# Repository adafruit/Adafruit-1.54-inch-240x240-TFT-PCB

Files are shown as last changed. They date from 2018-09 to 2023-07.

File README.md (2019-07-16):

## Adafruit 1.54" 240x240 Wide Angle TFT LCD Display with MicroSD - ST7789 PCB

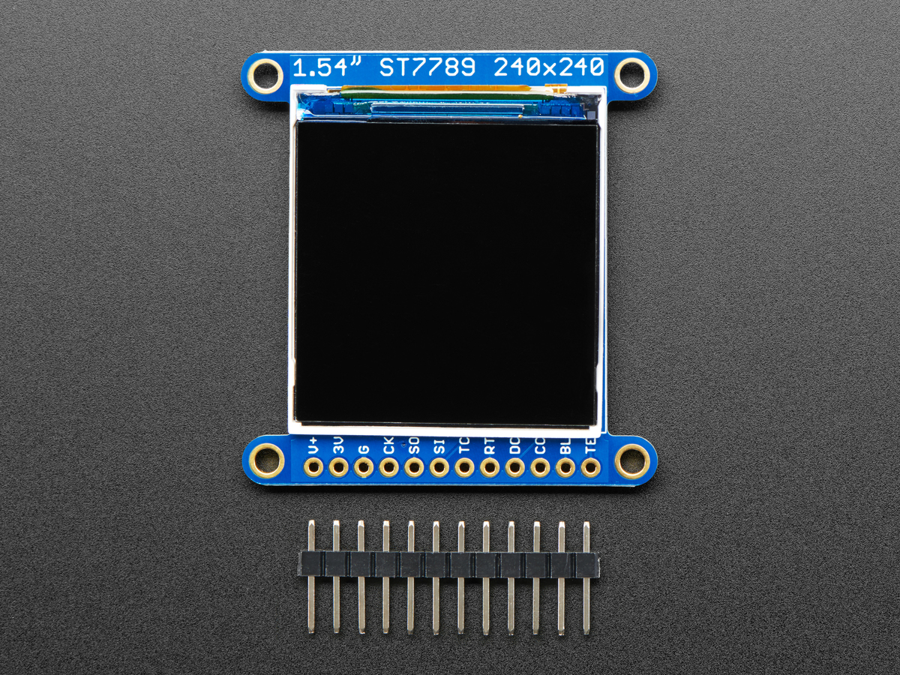
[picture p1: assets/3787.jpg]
<a href="http://www.adafruit.com/products/3787"><br/>
Click here to purchase one from the Adafruit shop</a>

PCB files for the Adafruit 1.54" 240x240 Wide Angle TFT LCD Display with MicroSD - ST7789. Format is EagleCAD schematic and board layout
* https://www.adafruit.com/product/3787

### Description

We've been looking for a display like this for a long time - it's only 1.5" diagonal but has a high density 220 ppi, 240x240 pixel display with full-angle viewing. It looks a lot like our 1.44" 128x128 display, but has 4x as many pixels and looks great at any angle. We've seen displays of this caliber used in smartwatches and small electronic devices but they've always been MIPI interface. Finally, we found one that is SPI and has a friendly display driver, so it works with any and all microcontrollers or microcomputers!

This lovely little display breakout is the best way to add a small, colorful and very bright display to any project. Since the display uses 4-wire SPI to communicate and has its own pixel-addressable frame buffer, it can be used with every kind of microcontroller. Even a very small one with low memory and few pins available! The 1.54" display has 240x240 16-bit full color pixels and is an **IPS** display, so the color looks great up to 80 degrees off axis in any direction. The TFT driver (ST7789) is very similar to the popular ST7735, and our Arduino library supports it well.

Our breakout has the TFT display soldered on (it uses a delicate flex-circuit connector) as well as a ultra-low-dropout 3.3V regulator and a 3/5V level shifter so you can use it with 3.3V or 5V power and logic. We also had a little space so we placed a microSD card holder so you can easily load full color bitmaps from a FAT16/FAT32 formatted microSD card. The microSD card is not included, [but you can pick one up here](http://www.adafruit.com/products/102) .

Of course, we wouldn't just leave you with a datasheet and a "good luck!" - [we've written a full open source graphics library that can draw pixels, lines, rectangles, circles, text and bitmaps as well as example code and a wiring tutorial.](http://learn.adafruit.com/1-8-tft-display) The code is written for Arduino but can be easily ported to your favorite microcontroller!

**Please note!** This display is designed original for smart watches and similar, where there's a glass over the screen. Without something gently holding the screen down, the backlight can eventually peel away from the TFT. (It's not destructive but it's unattractive) You can prevent this by, ideally, adding a plastic or glass cover/overlay. If using bare, try dabbing a touch of T6000 or similar craft glue on the thin side edges, or using a thin piece of tape to keep the front TFT attached to the backlight. We're trying to find a display without this annoyance, but these displays don't have a lot of manufacturers so pickin's are slim!

### License

Adafruit invests time and resources providing this open source design, please support Adafruit and open-source hardware by purchasing products from [Adafruit](https://www.adafruit.com)!

Designed by Limor Fried/Ladyada for Adafruit Industries.

Creative Commons Attribution/Share-Alike, all text above must be included in any redistribution. See license.txt for additional details.

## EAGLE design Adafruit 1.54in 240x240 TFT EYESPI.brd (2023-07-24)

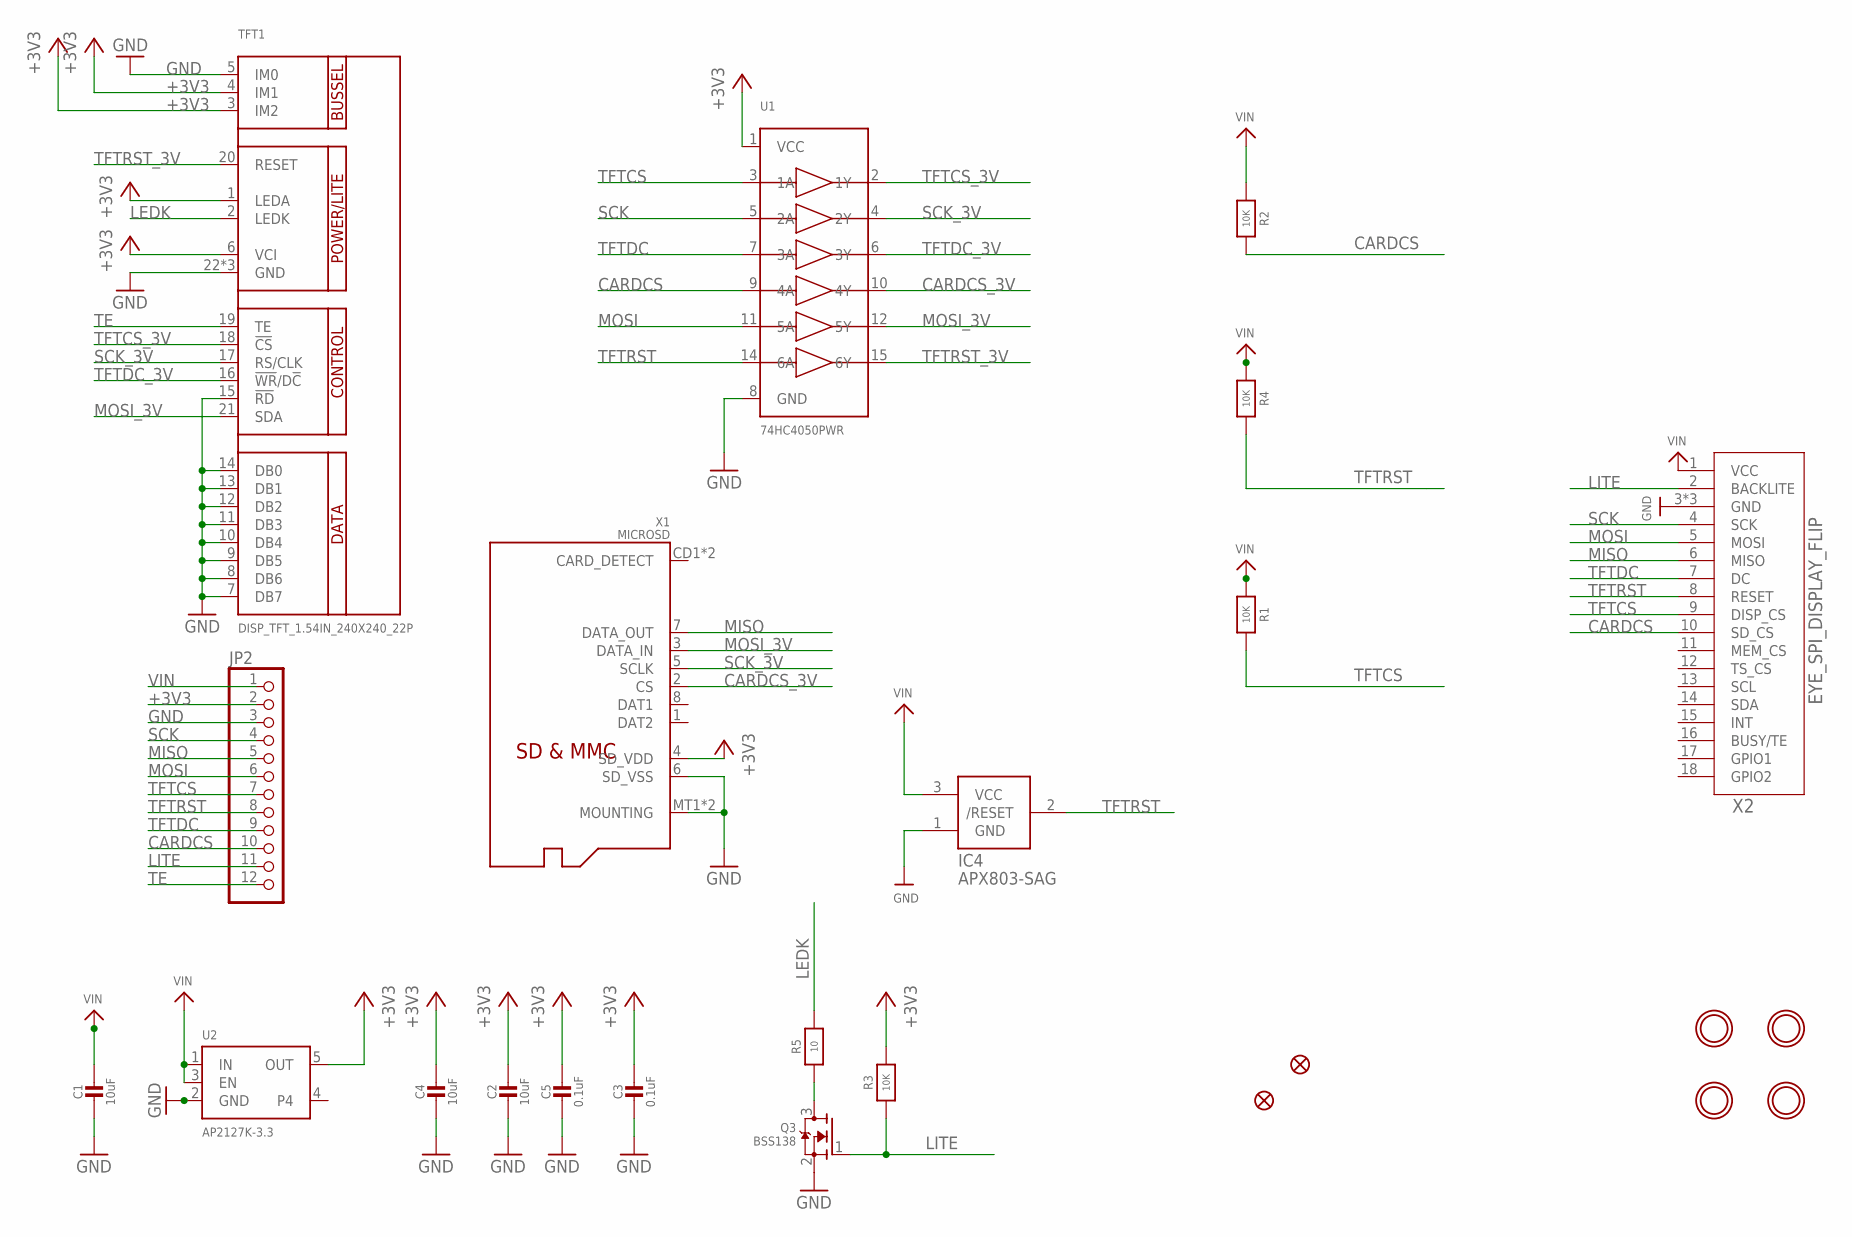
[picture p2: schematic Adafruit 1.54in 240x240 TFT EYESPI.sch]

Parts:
C1, C2, C4: 10uF; 0805-NO
C3, C5: 0.1uF; 0603-NO
IC4: APX803-SAG; SOT23-WIDE
JP2: HEADER-1X1276MIL; 1X12_ROUND_76MIL
Q3: BSS138; SOT23-WIDE
R1, R2, R3, R4: 10K; 0603-NO
R5: 10; 0603-NO
TFT1: DISP_TFT_1.54IN_240X240_22P; TFT_1.54IN_240X240_22PIN
U1: 74HC4050PWR; TSSOP16
U2: AP2127K-3.3; SOT23-5
U$4, U$5: FIDUCIAL_1MM
U$7, U$8, U$9, U$10: MOUNTINGHOLE2.5; MOUNTINGHOLE_2.5_PLATED
X1: MICROSD
X2: EYE_SPI_DISPLAY_FLIP; EYE_SPI_DISPLAY_BOTCONTACT

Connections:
+3V3: C2.1, C3.1, C4.1, C5.1, JP2.2, R3.2, TFT1.1 (LEDA), TFT1.3 (IM2), TFT1.4 (IM1), TFT1.6 (VCI), U1.1 (VCC), U2.5 (OUT), X1.4 (SD_VDD)
CARDCS: JP2.10, R2.1, U1.9 (4A), X2.10 (SD_CS)
CARDCS_3V: U1.10 (4Y), X1.2 (CS)
GND: C1.2, C2.2, C3.2, C4.2, C5.2, IC4.1 (GND), JP2.3, Q3.2 (S), TFT1.5 (IM0), TFT1.7 (DB7), TFT1.8 (DB6), TFT1.9 (DB5), TFT1.10 (DB4), TFT1.11 (DB3), TFT1.12 (DB2), TFT1.13 (DB1), TFT1.14 (DB0), TFT1.15 (!RD), TFT1.22 (GND), TFT1.SUPPORT1 (GND), TFT1.SUPPORT2 (GND), U1.8 (GND), U2.2 (GND), X1.6 (SD_VSS), X1.MT1 (MOUNTING), X1.MT2 (MOUNTING), X2.3 (GND), X2.SUPPORT1 (GND), X2.SUPPORT2 (GND)
LEDK: R5.2, TFT1.2 (LEDK)
LITE: JP2.11, Q3.1 (G), R3.1, X2.2 (BACKLITE)
MISO: JP2.5, X1.7 (DATA_OUT), X2.6 (MISO)
MOSI: JP2.6, U1.11 (5A), X2.5 (MOSI)
MOSI_3V: TFT1.21 (SDA), U1.12 (5Y), X1.3 (DATA_IN)
unnamed: Q3.3 (D), R5.1
SCK: JP2.4, U1.5 (2A), X2.4 (SCK)
SCK_3V: TFT1.17 (RS/CLK), U1.4 (2Y), X1.5 (SCLK)
TE: JP2.12, TFT1.19 (TE)
TFTCS: JP2.7, R1.1, U1.3 (1A), X2.9 (DISP_CS)
TFTCS_3V: TFT1.18 (!CS), U1.2 (1Y)
TFTDC: JP2.9, U1.7 (3A), X2.7 (DC)
TFTDC_3V: TFT1.16 (!WR!/D!C), U1.6 (3Y)
TFTRST: IC4.2 (/RESET), JP2.8, R4.1, U1.14 (6A), X2.8 (RESET)
TFTRST_3V: TFT1.20 (RESET), U1.15 (6Y)
VIN: C1.1, IC4.3 (VCC), JP2.1, R1.2, R2.2, R4.2, U2.1 (IN), U2.3 (EN), X2.1 (VCC)

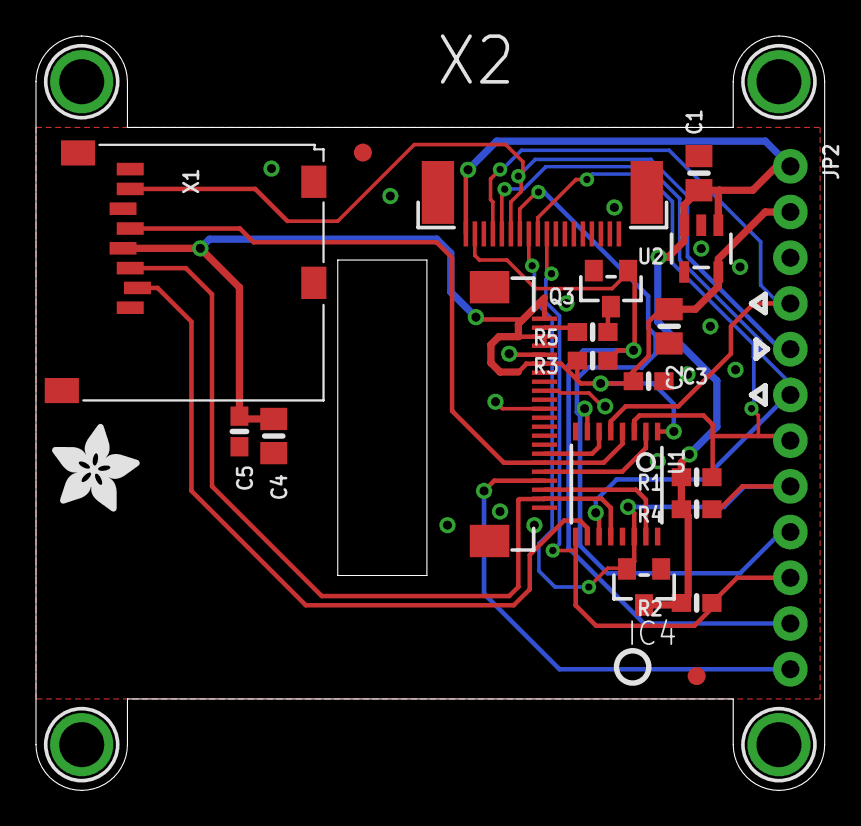
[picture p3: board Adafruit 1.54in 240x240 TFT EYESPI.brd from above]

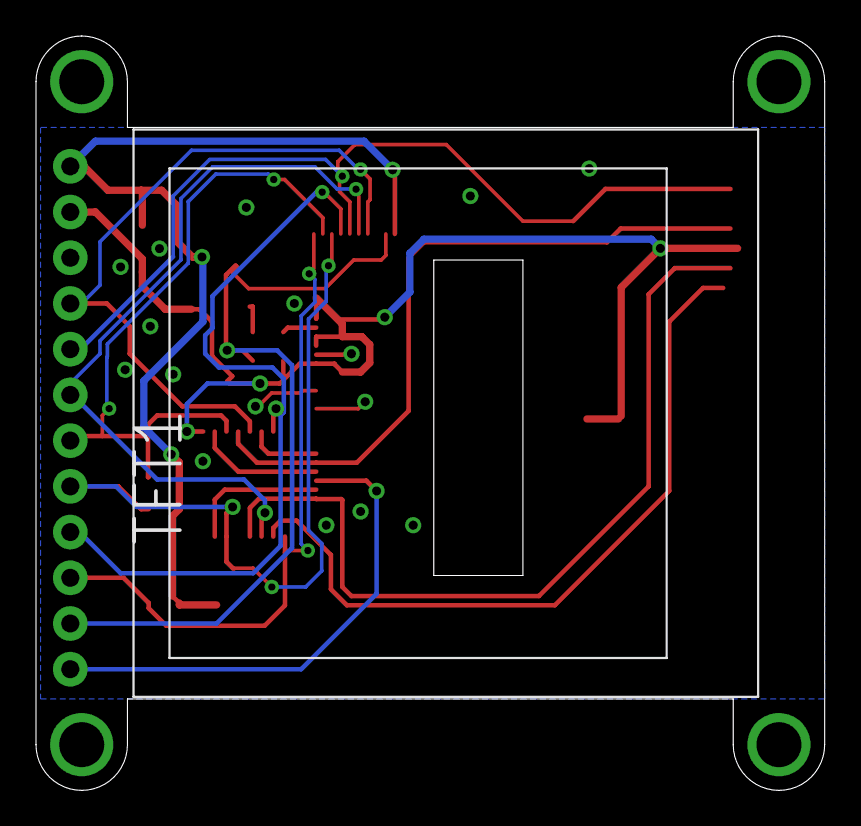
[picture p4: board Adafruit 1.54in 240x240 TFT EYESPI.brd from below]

Board: 2 copper layers, 43.8 x 41.9 mm, 56 parts (14 on the bottom side), 20 nets.

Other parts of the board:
PLABEL0: PLABEL0
PLABEL1: PLABEL1
PLABEL2: PLABEL2
PLABEL3: PLABEL3
PLABEL4: PLABEL4
PLABEL5: PLABEL5
PLABEL6: PLABEL6
PLABEL7: PLABEL7
PLABEL8: PLABEL8
PLABEL9: PLABEL9
PLABEL10: PLABEL10
PLABEL11: PLABEL11
PLABEL12: PLABEL12
PLABEL13: PLABEL13
PLABEL14: PLABEL14
PLABEL15: PLABEL15
PLABEL16: PLABEL16
PLABEL17: PLABEL17
PLABEL18: PLABEL18
PLABEL19: PLABEL19
PLABEL20: PLABEL20
PLABEL21: PLABEL21
PLABEL22: PLABEL22
PLABEL23: PLABEL23
PLABEL24: PLABEL24
PLABEL25: PLABEL25
PLABEL26: PLABEL26
PLABEL27: PLABEL27
PLABEL28: PLABEL28
PLABEL29: PLABEL29
U$1: ADAFRUIT_5MM
U$2: PCBFEAT-REV-040

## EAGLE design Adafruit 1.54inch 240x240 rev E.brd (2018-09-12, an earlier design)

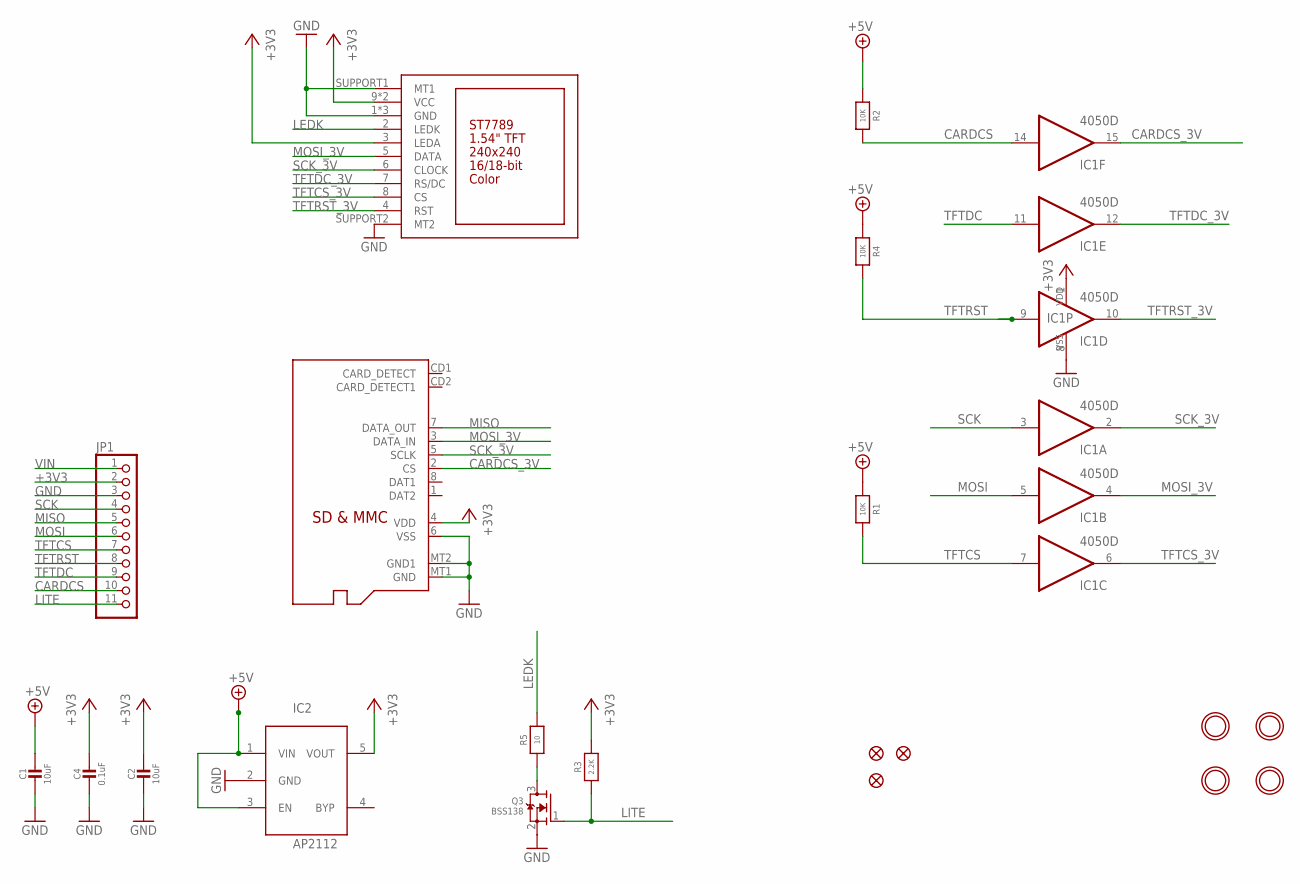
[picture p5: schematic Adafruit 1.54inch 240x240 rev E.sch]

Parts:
C1, C2: 10uF; 0805-NO
C4: 0.1uF; 0805-NO
DISP1: DISP_LCD_ST7789_1.54IN; TFT_1.54IN_240X240
IC1: 4050D; SO16
IC2: AP2112; SOT23-5L
JP1: HEADER-1X1176MIL; 1X11_ROUND_76
Q2: MICROSD
Q3: BSS138; SOT23-WIDE
R1, R2, R4: 10K; 0805-NO
R3: 2.2K; 0805-NO
R5: 10; 0805-NO
U$3, U$4, U$5: FIDUCIAL_1MM
U$7, U$8, U$9, U$10: MOUNTINGHOLE2.5; MOUNTINGHOLE_2.5_PLATED

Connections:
+3V3: C2.1, C4.1, DISP1.3 (LEDA), DISP1.9 (VCC), DISP1.10 (VCC), IC1.1 (VDD), IC2.5 (VOUT), JP1.2, Q2.4 (VDD), R3.2
CARDCS: IC1.14 (I), JP1.10, R2.1
CARDCS_3V: IC1.15 (O), Q2.2 (CS)
GND: C1.2, C2.2, C4.2, DISP1.1 (GND), DISP1.11 (GND), DISP1.12 (GND), DISP1.SUPPORT1 (MT1), DISP1.SUPPORT2 (MT2), IC1.8 (VSS), IC2.2 (GND), JP1.3, Q2.6 (VSS), Q2.MT1 (GND), Q2.MT2 (GND1), Q3.2 (S)
LEDK: DISP1.2 (LEDK), R5.2
LITE: JP1.11, Q3.1 (G), R3.1
MISO: JP1.5, Q2.7 (DATA_OUT)
MOSI: IC1.5 (I), JP1.6
MOSI_3V: DISP1.5 (DATA), IC1.4 (O), Q2.3 (DATA_IN)
unnamed: Q3.3 (D), R5.1
SCK: IC1.3 (I), JP1.4
SCK_3V: DISP1.6 (CLOCK), IC1.2 (O), Q2.5 (SCLK)
TFTCS: IC1.7 (I), JP1.7, R1.1
TFTCS_3V: DISP1.8 (CS), IC1.6 (O)
TFTDC: IC1.11 (I), JP1.9
TFTDC_3V: DISP1.7 (RS/DC), IC1.12 (O)
TFTRST: IC1.9 (I), JP1.8, R4.1
TFTRST_3V: DISP1.4 (RST), IC1.10 (O)
VIN: C1.1, IC2.1 (VIN), IC2.3 (EN), JP1.1, R1.2, R2.2, R4.2

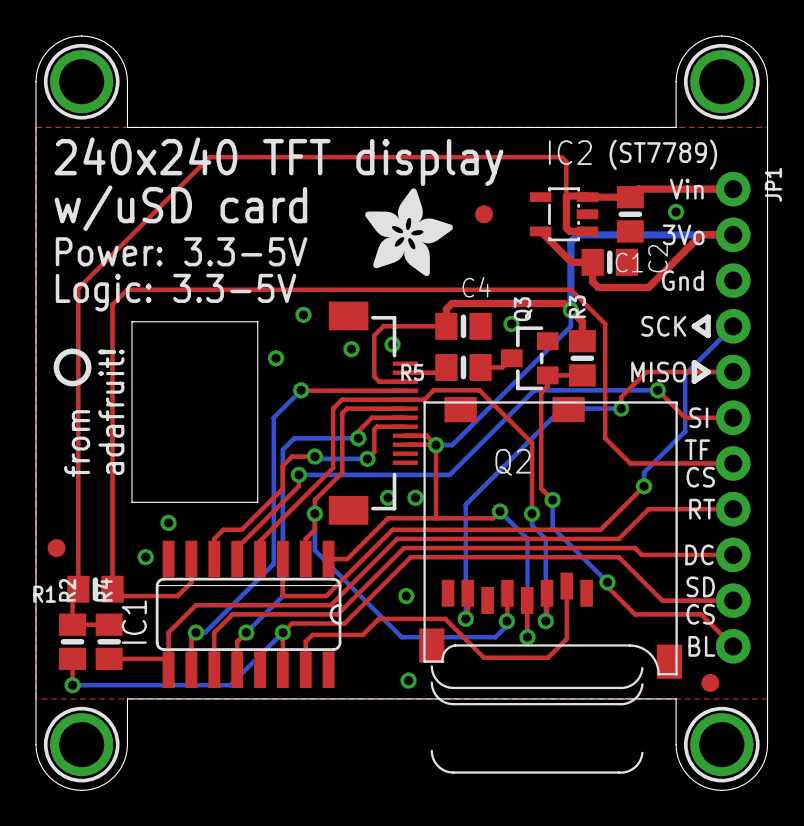
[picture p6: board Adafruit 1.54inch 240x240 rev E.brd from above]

Board: 2 copper layers, 40.6 x 41.9 mm, 23 parts (1 on the bottom side), 19 nets.

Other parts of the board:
U$1: ADAFRUIT_5MM
U$2: PCBFEAT-REV-040

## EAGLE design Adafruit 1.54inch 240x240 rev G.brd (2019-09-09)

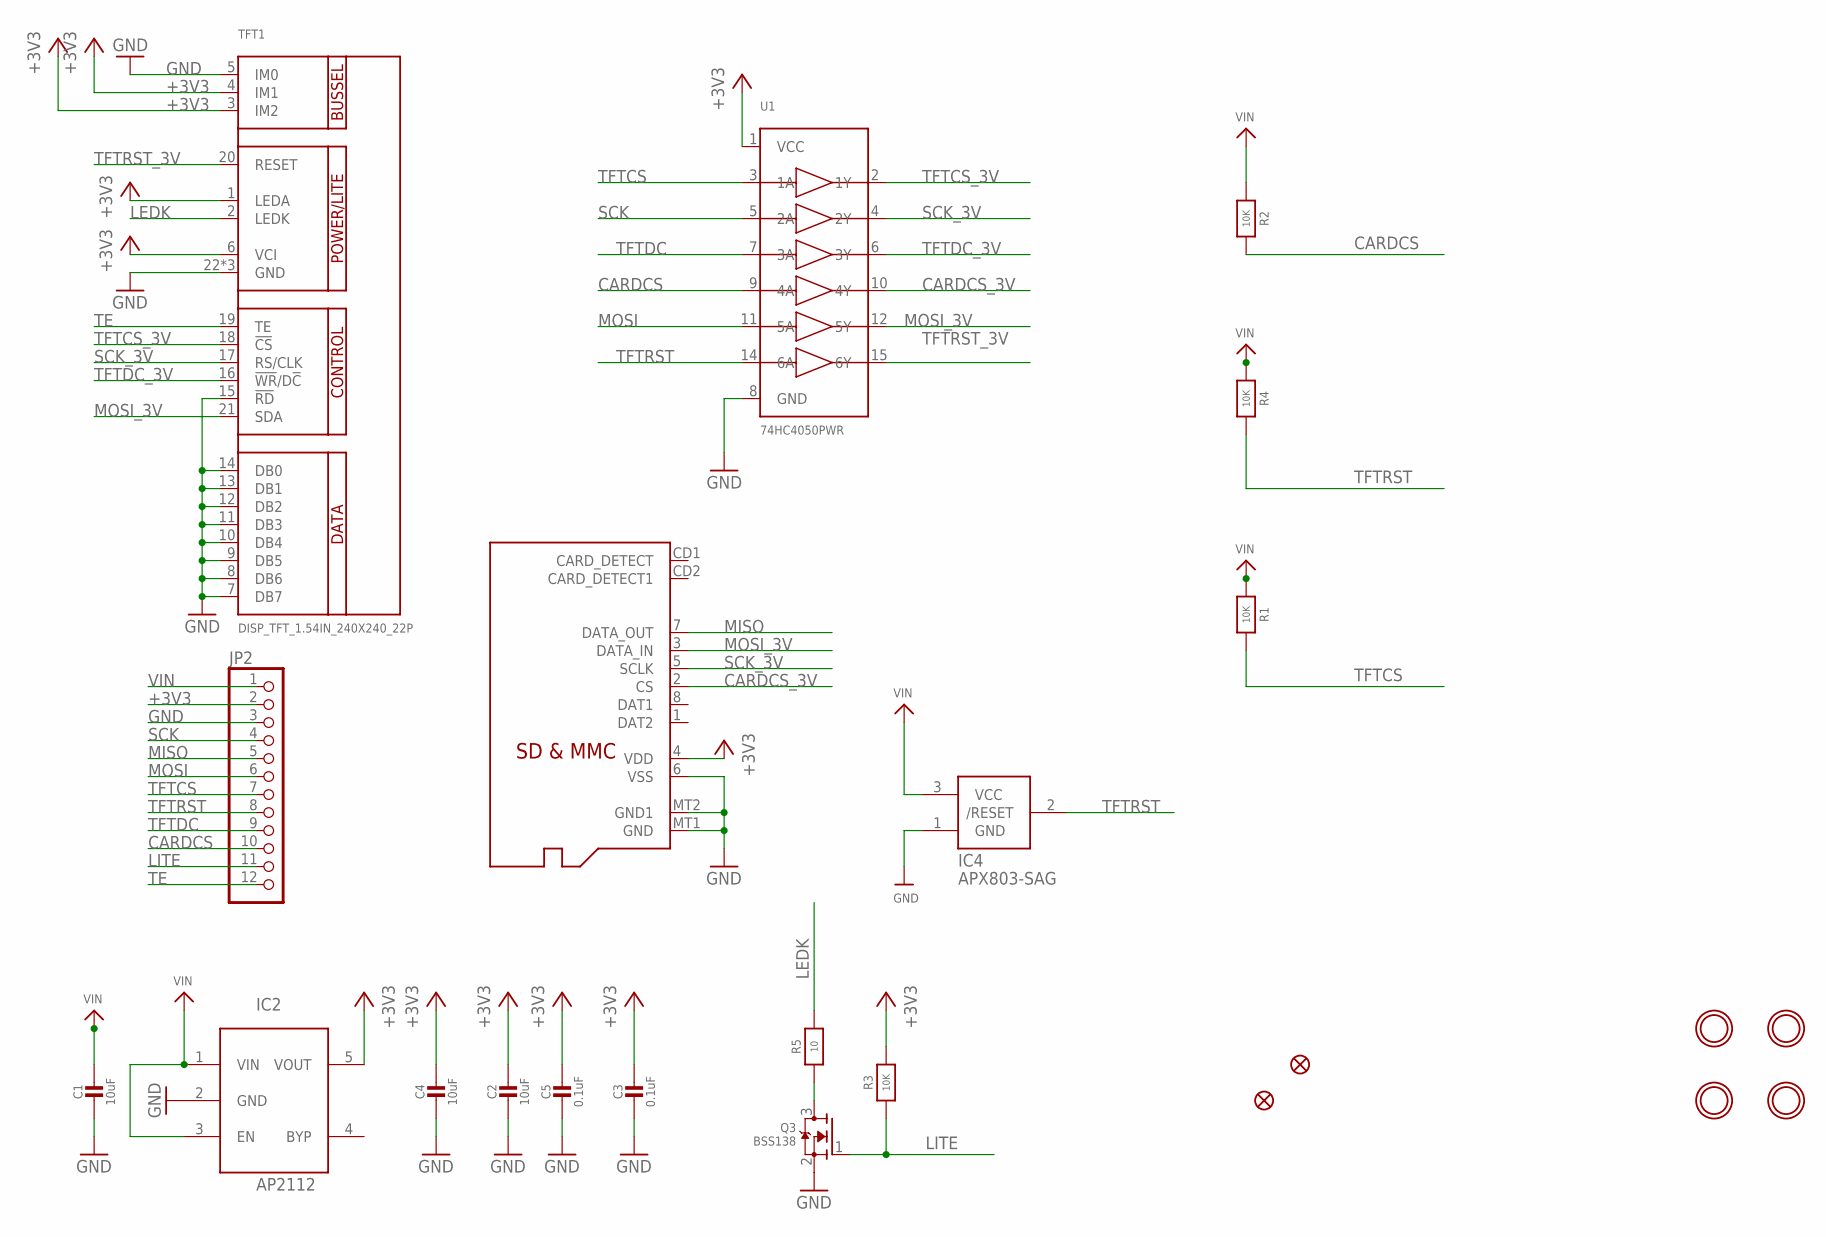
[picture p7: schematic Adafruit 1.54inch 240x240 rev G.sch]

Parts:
C1, C2, C4: 10uF; 0805-NO
C3, C5: 0.1uF; 0603-NO
IC2: AP2112; SOT23-5L
IC4: APX803-SAG; SOT23
JP2: HEADER-1X1276MIL; 1X12_ROUND_76MIL
Q2: MICROSD
Q3: BSS138; SOT23-WIDE
R1, R2, R3, R4: 10K; 0603-NO
R5: 10; 0603-NO
TFT1: DISP_TFT_1.54IN_240X240_22P; TFT_1.54IN_240X240_22PIN
U1: 74HC4050PWR; TSSOP16
U$4, U$5: FIDUCIAL_1MM
U$7, U$8, U$9, U$10: MOUNTINGHOLE2.5; MOUNTINGHOLE_2.5_PLATED

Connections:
+3V3: C2.1, C3.1, C4.1, C5.1, IC2.5 (VOUT), JP2.2, Q2.4 (VDD), R3.2, TFT1.1 (LEDA), TFT1.3 (IM2), TFT1.4 (IM1), TFT1.6 (VCI), U1.1 (VCC)
CARDCS: JP2.10, R2.1, U1.9 (4A)
CARDCS_3V: Q2.2 (CS), U1.10 (4Y)
GND: C1.2, C2.2, C3.2, C4.2, C5.2, IC2.2 (GND), IC4.1 (GND), JP2.3, Q2.6 (VSS), Q2.MT1 (GND), Q2.MT2 (GND1), Q3.2 (S), TFT1.5 (IM0), TFT1.7 (DB7), TFT1.8 (DB6), TFT1.9 (DB5), TFT1.10 (DB4), TFT1.11 (DB3), TFT1.12 (DB2), TFT1.13 (DB1), TFT1.14 (DB0), TFT1.15 (!RD), TFT1.22 (GND), TFT1.SUPPORT1 (GND), TFT1.SUPPORT2 (GND), U1.8 (GND)
LEDK: R5.2, TFT1.2 (LEDK)
LITE: JP2.11, Q3.1 (G), R3.1
MISO: JP2.5, Q2.7 (DATA_OUT)
MOSI: JP2.6, U1.11 (5A)
MOSI_3V: Q2.3 (DATA_IN), TFT1.21 (SDA), U1.12 (5Y)
unnamed: Q3.3 (D), R5.1
SCK: JP2.4, U1.5 (2A)
SCK_3V: Q2.5 (SCLK), TFT1.17 (RS/CLK), U1.4 (2Y)
TE: JP2.12, TFT1.19 (TE)
TFTCS: JP2.7, R1.1, U1.3 (1A)
TFTCS_3V: TFT1.18 (!CS), U1.2 (1Y)
TFTDC: JP2.9, U1.7 (3A)
TFTDC_3V: TFT1.16 (!WR!/D!C), U1.6 (3Y)
TFTRST: IC4.2 (/RESET), JP2.8, R4.1, U1.14 (6A)
TFTRST_3V: TFT1.20 (RESET), U1.15 (6Y)
VIN: C1.1, IC2.1 (VIN), IC2.3 (EN), IC4.3 (VCC), JP2.1, R1.2, R2.2, R4.2

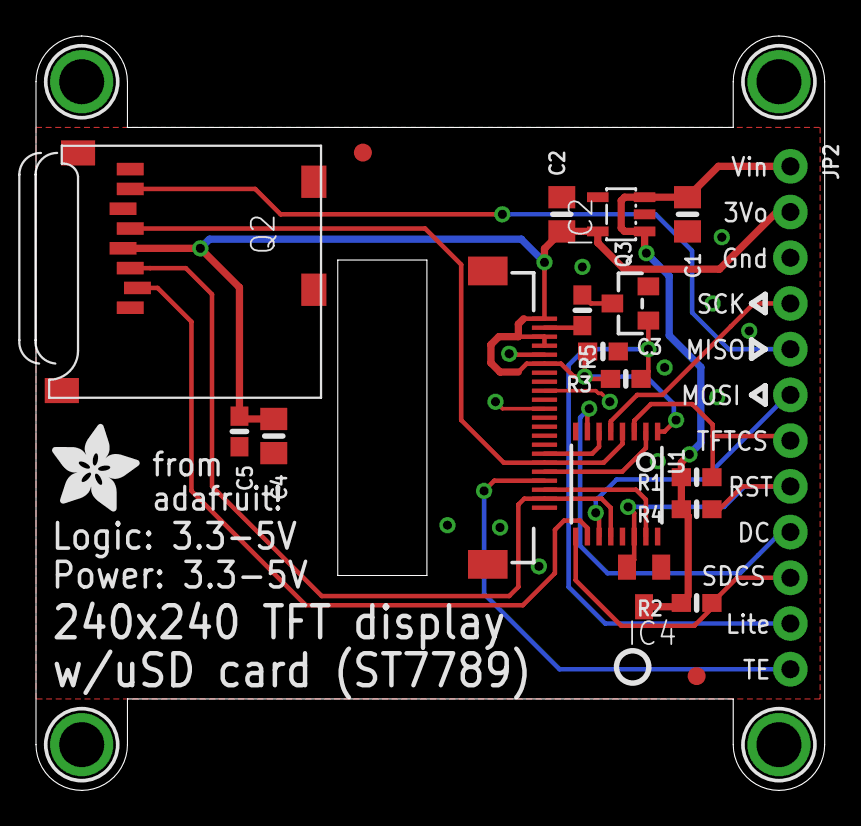
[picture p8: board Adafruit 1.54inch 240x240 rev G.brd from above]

Board: 2 copper layers, 43.8 x 41.9 mm, 25 parts (1 on the bottom side), 20 nets.

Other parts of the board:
U$1: ADAFRUIT_5MM
U$2: PCBFEAT-REV-040

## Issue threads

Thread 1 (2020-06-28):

Please post Rev E .sch and .brd of this board

sbennison, 2020-06-28:
I have the older rev E board without the TE pin. Could you include the Rev E files?
Much appreciated!

kattni, 2020-06-29:
@sbennison Done!

Closed 2020-06-29.

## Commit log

2019-07-16 updated to use new pcb repo cookiecutter
2019-08-07 Updating board files.
    [Adafruit 1.54inch 240x240.brd, Adafruit 1.54inch 240x240.sch]
2019-08-08 Removing to update to current version
2019-09-09 add rev G with 22pin display
    [Adafruit 1.54inch 240x240 rev G.brd, Adafruit 1.54inch 240x240 rev G.sch]
2020-06-29 Add rev E board files.
    [Adafruit 1.54inch 240x240 rev E.brd, Adafruit 1.54inch 240x240 rev E.sch]
2023-07-24 Add updated board files.
    [Adafruit 1.54in 240x240 TFT EYESPI.brd, Adafruit 1.54in 240x240 TFT EYESPI.sch]

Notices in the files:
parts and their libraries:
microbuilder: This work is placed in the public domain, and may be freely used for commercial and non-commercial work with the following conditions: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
